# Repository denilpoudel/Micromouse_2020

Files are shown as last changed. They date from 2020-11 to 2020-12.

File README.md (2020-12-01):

# Micromouse 2020

| | Version 1 | Version 2 |
| --- | --- | --- |
| Width | 100mm | ? |
| Height | 80mm | ? |
| MPU | ESP32-WROOM-32U  | ESP32-WROOM-32D |
| IR EMITTER | VSLY5940 | VSLY5940 |
| IR RECIEVER | TSSP58P38 | ? |
| MOTOR | 75:1 Micro Metal Gearbox 6V | 75:1 Micro Metal Gearbox 6V |
| ENCODER | 12 Count Magnetic | 12 Count Magnetic |
| BATTERY |  RDQ 7.6 2s 650mAH LiPo | ? |
| POWER |  TPS63070RNMR @ 7.4V 2A TPS62147RGXR @ 5.0V 2A TPS62147RGXR @ 3.3V 1A | ? |

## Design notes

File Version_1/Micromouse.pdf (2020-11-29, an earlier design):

# Micromouse

Big Rat
November 21, 2020
Denil Poudel
Worth Bistline
Vivian Dinh
Carlos Lazzo
Ken Ny

# Agenda

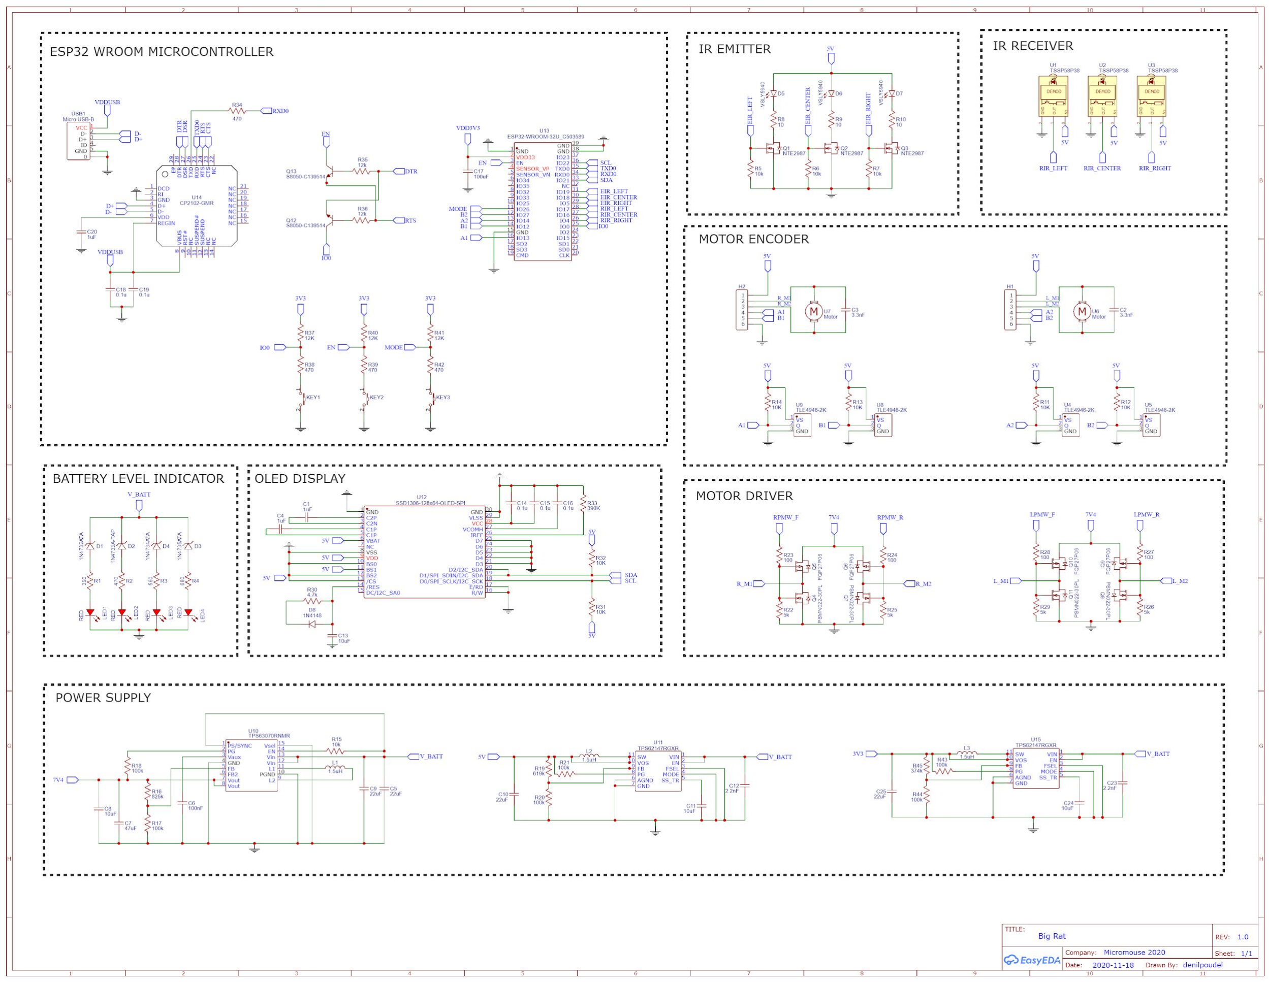
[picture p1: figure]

## - Overview - Design - Microprocessor - Design - Wall Detection - Design - Motor Control - Design - Power - Design - Algorithm - BoM - Schematic

# Big Rat Overview

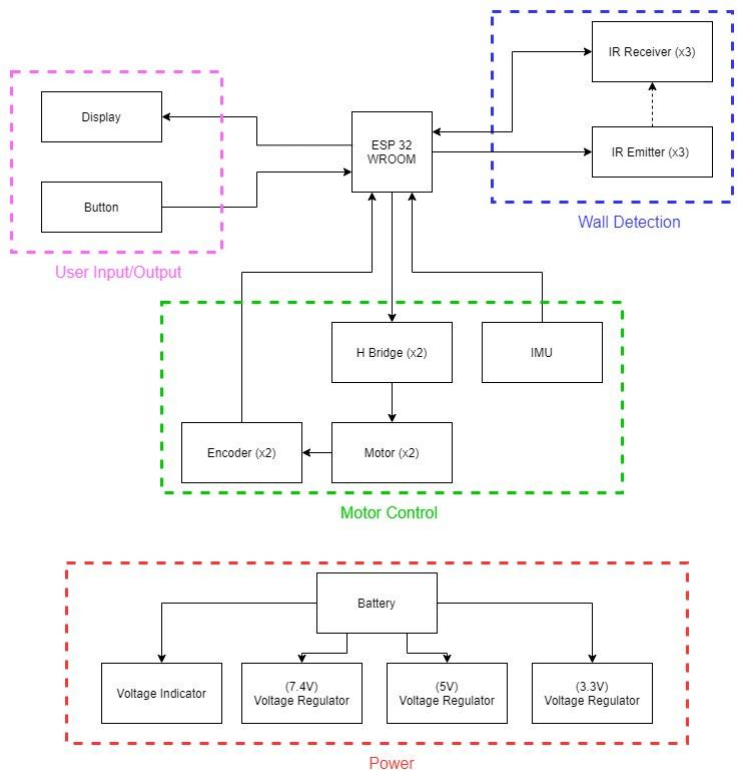
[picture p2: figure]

Dimensions:
Width: | 100mm
Length: | 80mm
| Hardware:
MPU: | ESP32 @240MHz

IR Emitter: VSLY5940 (940nm)
IR Receiver:TSSP58P38 (940nm)
Motor: | 75:1 Micro Metal Gearbox 6V
Encoder: | 12 Count Magnetic
Battery: | RDQ 7.6 2s 650mAH LiPo
Power: | TPS63070RNMR @ 7.4V 2A
| TPS62147RGXR @ 5.0V 2A
| TPS62147RGXR @ 3.3V 1A

# Big Rat Design - Microprocessor

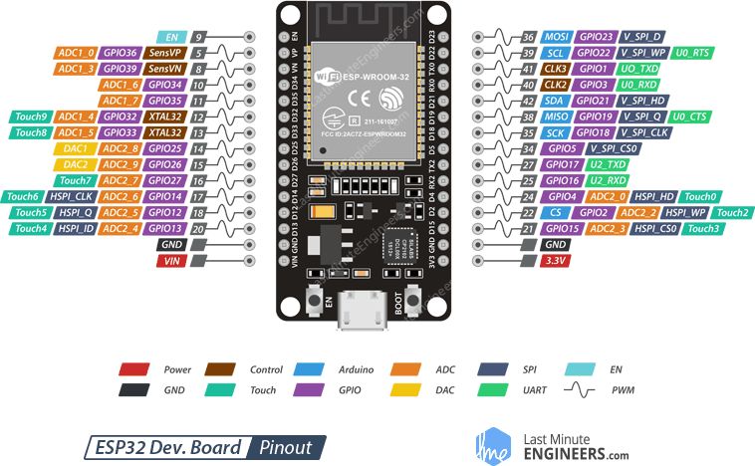
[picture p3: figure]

- ESP32
- Architecture: 32 bit
- Clock: 240MHz
- Core: 2
- PWM: 16 Channels
■ MAX: 40MHz
- Arduino Nano
- Architecture: 16 bit
- Clock: 16MHz
- Core: 1
- PWM: 6 Channels
■ MAX: 490Hz

# Big Rat Design - Wall Detection (IR Emitter)

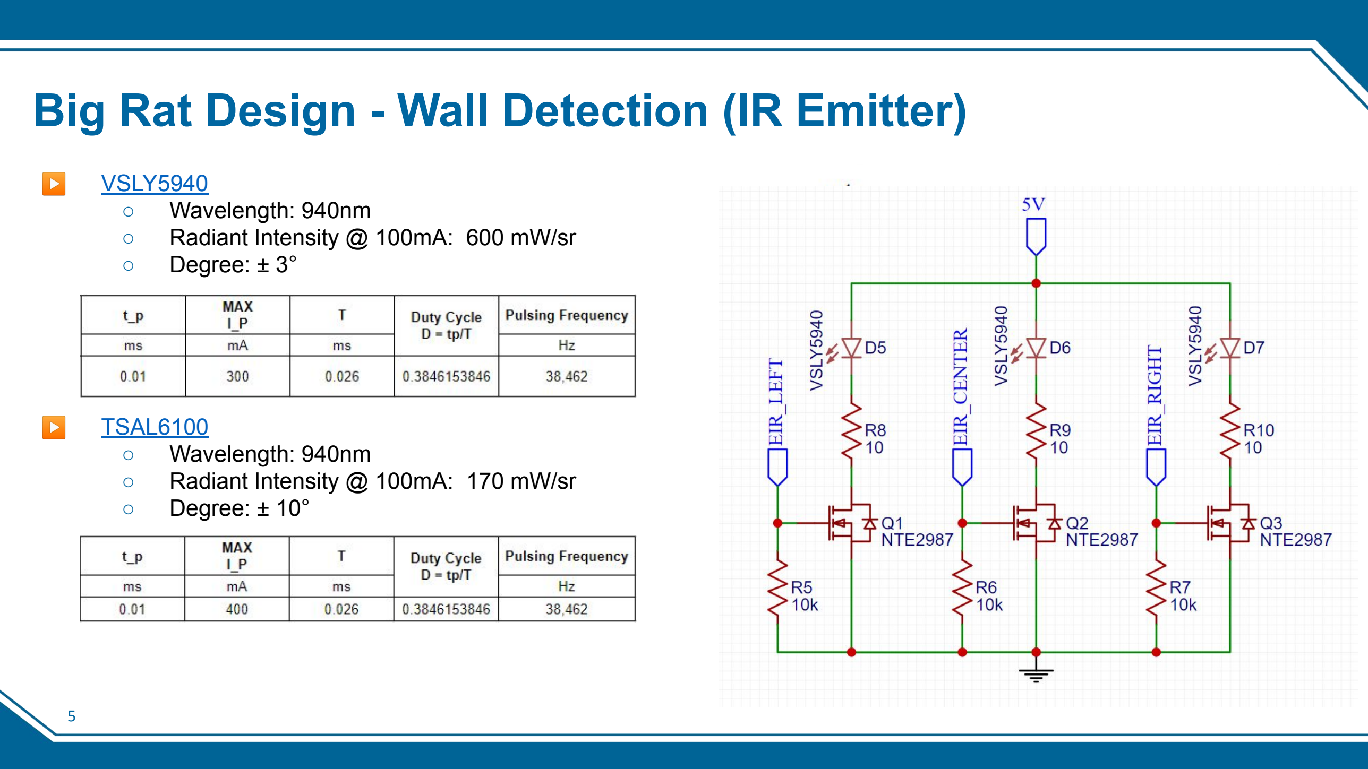
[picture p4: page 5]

- VSLY5940 (https://www.vishay.com/docs/84240/vsly5940.pdf)
- Wavelength: 940nm
- Radiant Intensity @ 100mA: 600 mW/sr
- Degree: ± 3°
- TSAL6100 (https://www.vishay.com/docs/81009/tsal6100.pdf)
- Wavelength: 940nm
- Radiant Intensity @ 100mA: 170 mW/sr
- Degree: ± 10°

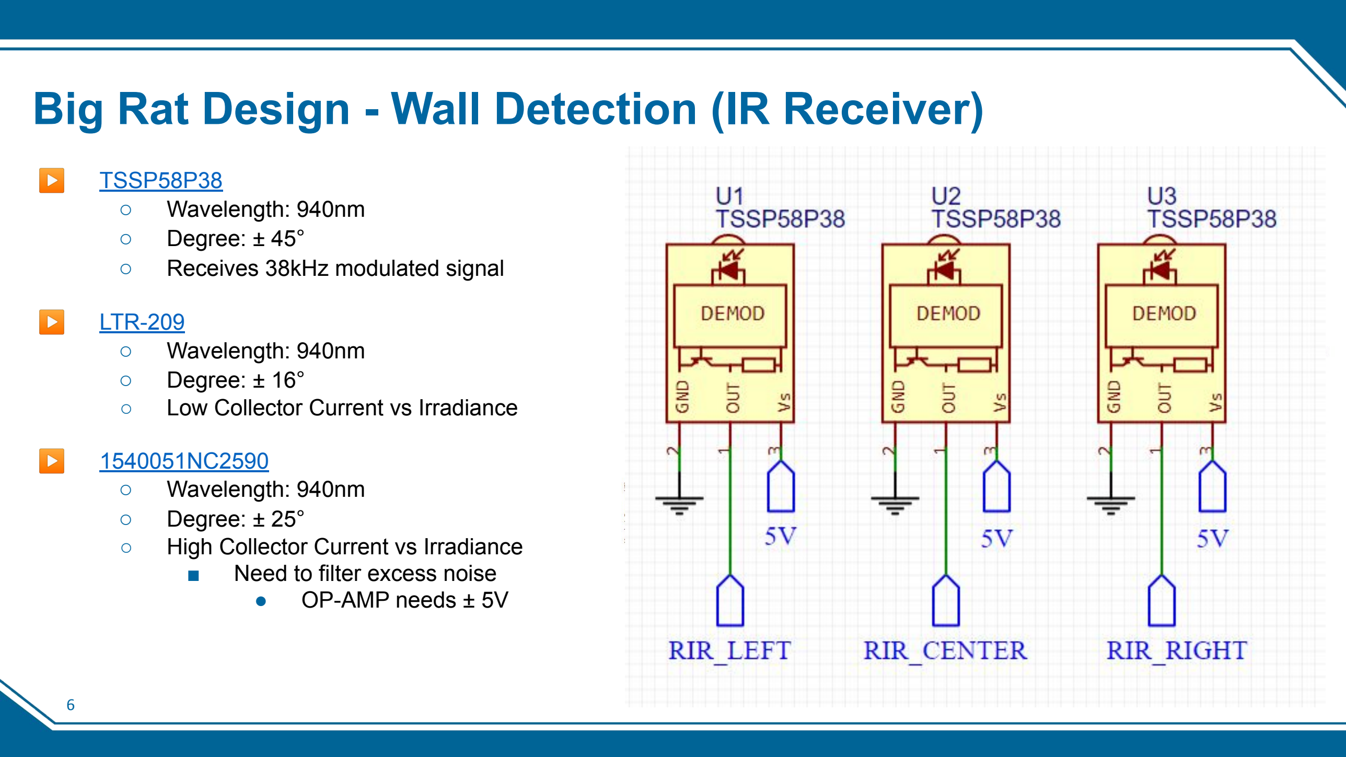
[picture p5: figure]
▶ TSSP58P38; ○ Wavelength: 940nm ○ Degree: ± 45° ○ Receives 38kHz modulated signal; ▶ LTR-209; ○ Wavelength: 940nm ○ Degree: ± 16° ○ Low Collector Current vs Irradiance; ○ Wavelength: 940nm ○ Degree: ± 25° ○ High Collector Current vs Irradiance; Need to filter excess noise; ● OP-AMP needs ± 5V

# Big Rat Design - Wall Detection (IR Receiver)

# Big Rat Design - Motor Control

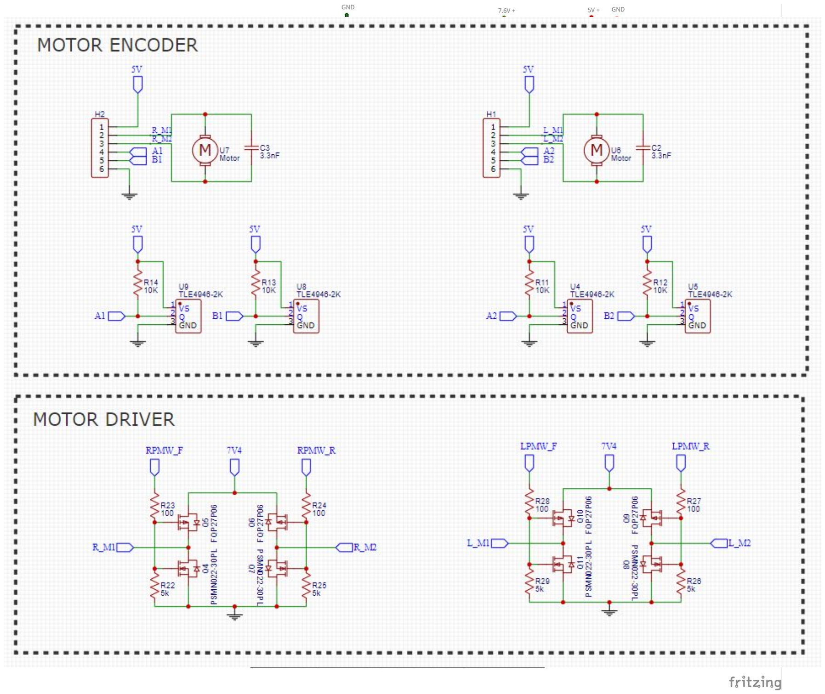
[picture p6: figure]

- H-Bridge
- Discrete H-Bridge
- L298N [Backup]
- Micro Metal Motor
- Brushed DC 6V
- 1:75 Gearbox
- Length: 45 mm
- Magnetic Encoder
- 12 Count [900 Count w/ Gearbox]
- Digital Control System
- Arduino PID Library (https://github.com/owhite/Arduino-PID-control) [ESP32 Compatible]
■ | Store data to EEPROM
■ | Plot data in Python

# Big Rat Design - Power

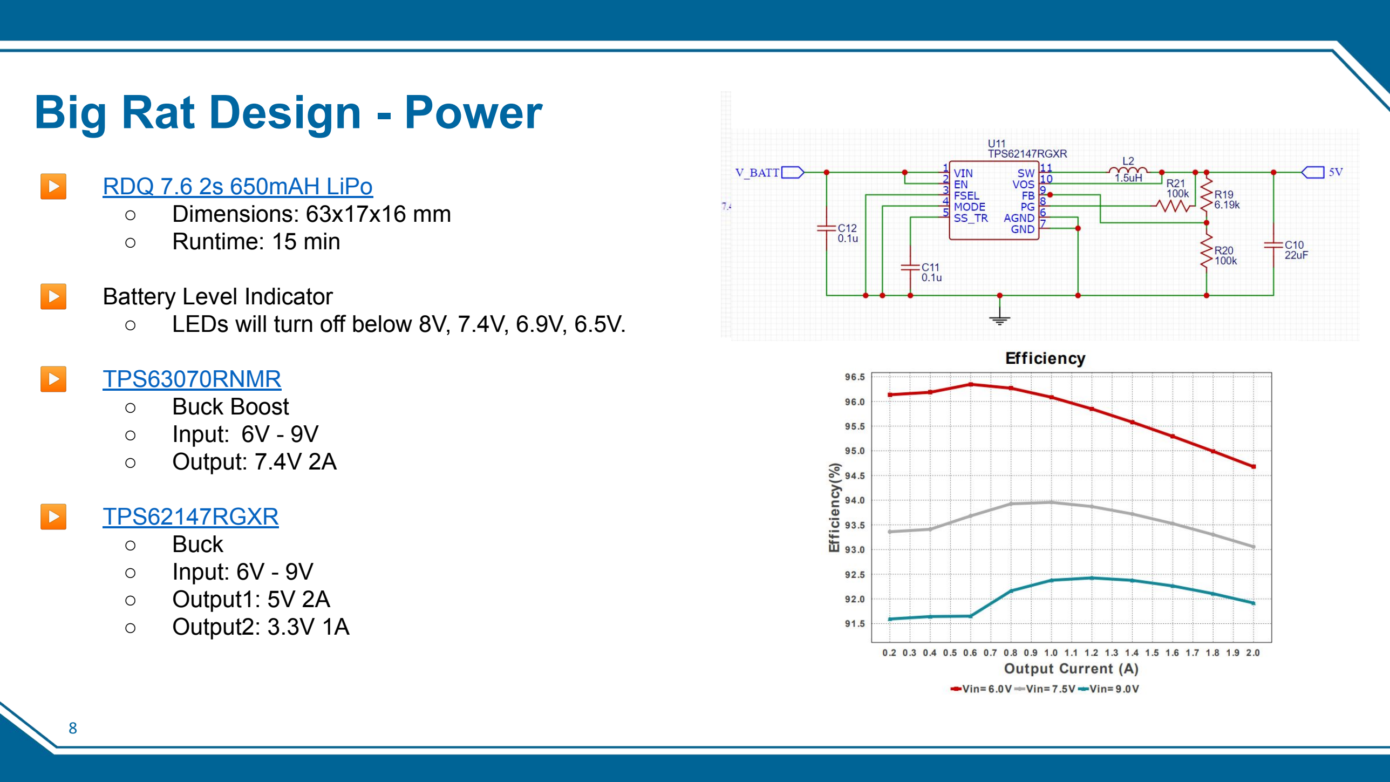
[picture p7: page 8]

Battery Voltage Levels

- RDQ 7.6 2s 650mAH LiPo (https://www.racedayquads.com/collections/mini-batteries/products/rdq-series-7-6v-2s-650mah-60c-lihv-battery-xt30)
- Dimensions: 63x17x16 mm
- Runtime: 15 min
- Battery Level Indicator
- LEDs will turn off below 8V, 7.4V, 6.9V, 6.5V.
- TPS63070RNMR (https://www.ti.com/lit/ds/symlink/tps63070.pdf?ts=1605816152647)
- Buck Boost
- Input: 6V - 9V
- Output: 7.4V 2A
- TPS62147RGXR (https://www.ti.com/lit/ds/symlink/tps62147.pdf?ts=1605822060273)
- Buck
- Input: 6V - 9V
- Output1: 5V 2A
- Output2: 3.3V 1A

Current Draw Calculation

# Big Rat Design - Algorithm

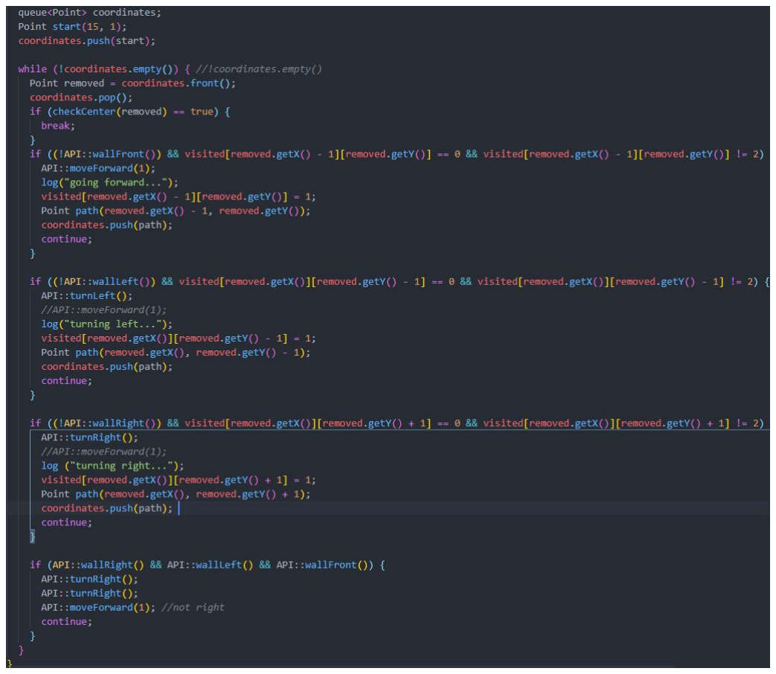
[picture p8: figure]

- MMS Simulator (https://github.com/mackorone/mms)
- Simulation testing C++ Algorithm
- Allows parallel development
- Breadth First Search
- Algorithm:
■ | Selects initial point in graph
■ | Visits all adjacent nodes to the selected
■ | Continues until all nodes in graph is visited
| and marked
- Simplest to implement
■ Does not have the fastest run time
- Will eventually switch algorithms
■ | A*
■ | Flood Fill
■ | Dijkstra’s

# Big Rat - BoM

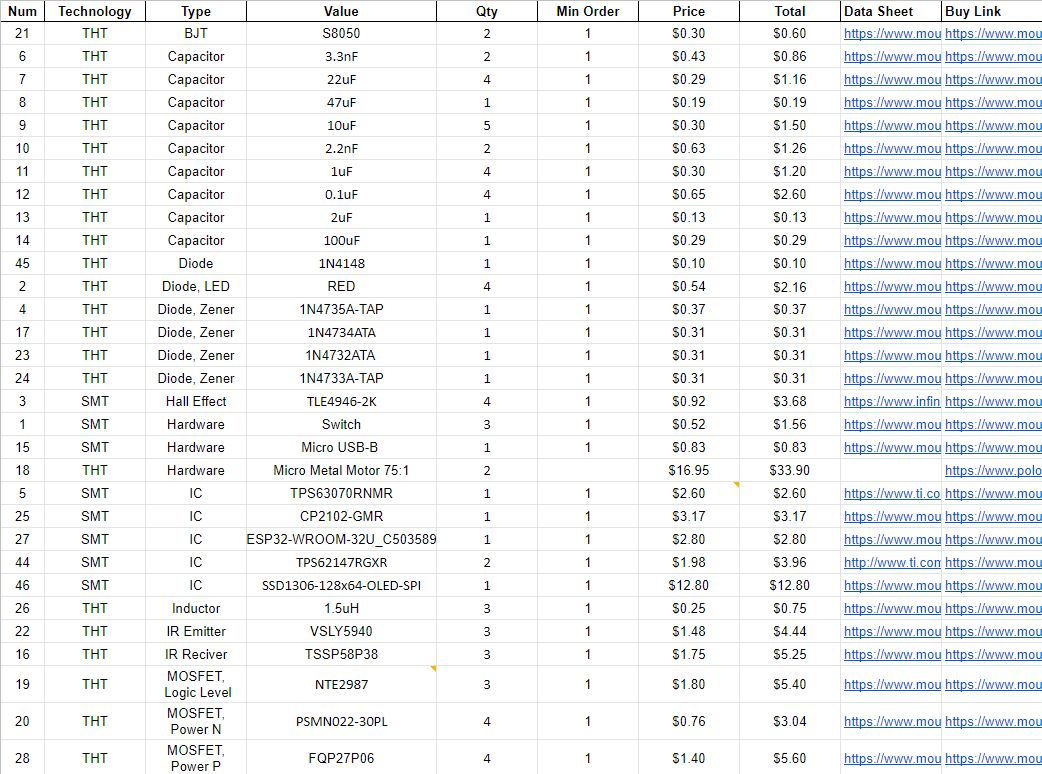
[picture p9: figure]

- Bill Of Material
- All Parts Available from Mouser
- 46 Different Components
■ Mix of THT and SMT ● Eventually all will be SMT
- Total Cost of Components: ~$120.06
- Some components out of stock
■ Working on finding alternatives
- PCB Fabrication
- Custom Home PCB Fabrication by Denil ■ JLCPCB - $10 for 5 Boards ● 3-5 Day Turn Around ● 4 Weeks Shipping

# Questions?

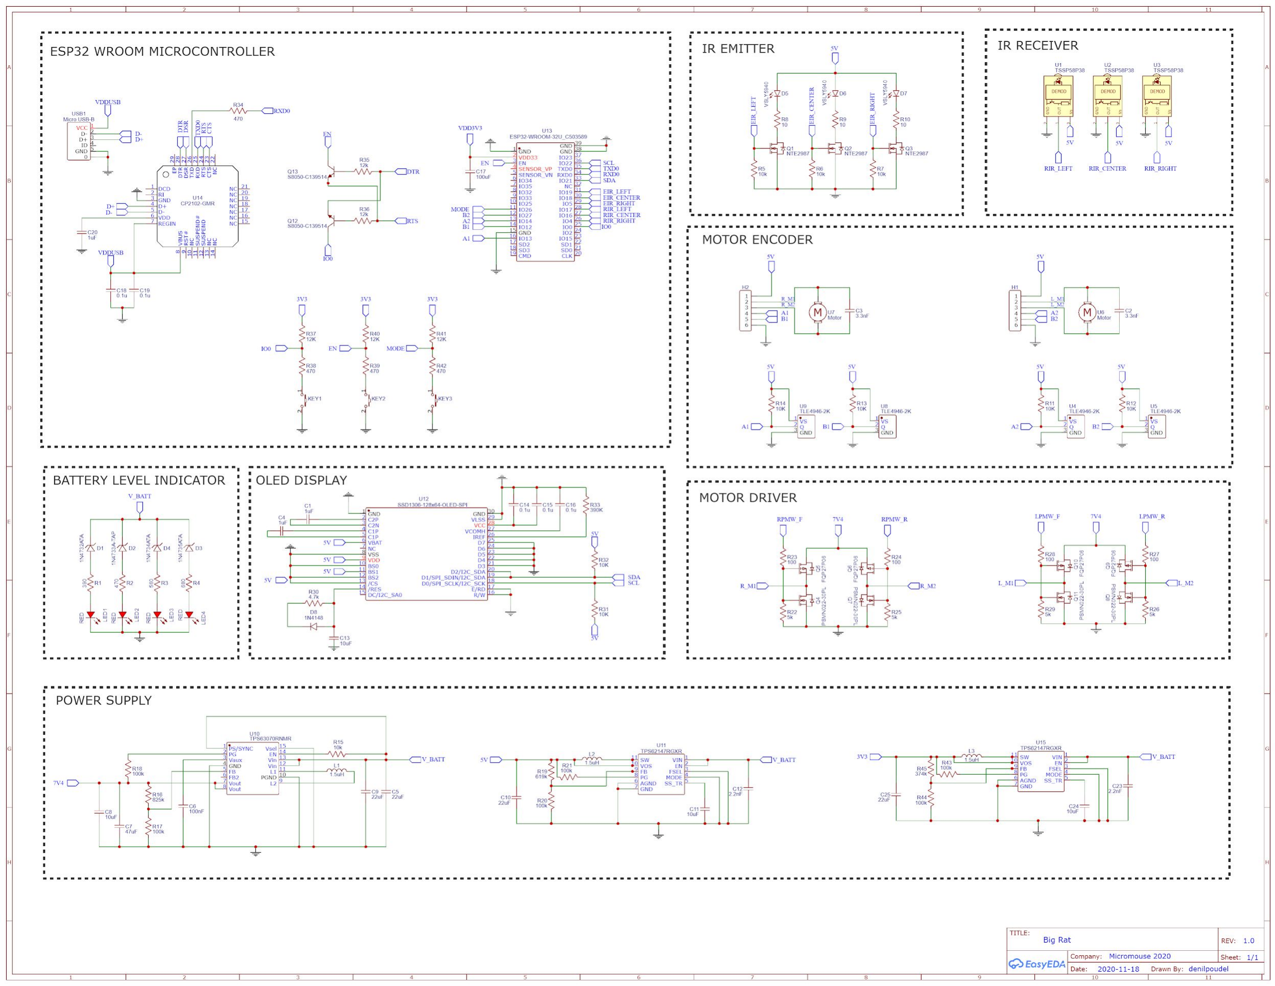
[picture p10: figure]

Schematic (https://drive.google.com/file/d/1DUR6l65qnsQ60jDtrFfjevxRQcCzWgwZ/view?usp=sharing)

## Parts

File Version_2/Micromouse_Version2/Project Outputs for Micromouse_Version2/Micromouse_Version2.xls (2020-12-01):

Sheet: Part List Report
 | Component list |  |  | Bill of Materials for Project [Micromouse_Version2.PrjPcb] (No PCB Document Selected)
 | Source Data From: |  |  | Micromouse_Version2.PrjPcb
 | Project: |  |  | Micromouse_Version2.PrjPcb
 | Variant: |  |  | None
 | Report Date: |  | 11/30/2020 | 15:29
 | Print Date: |  | 2020-11-30 | 15:29:13
# | LibRef | #Column Name Error:' Manufacturer 1 | #Column Name Error:' Manufacturer Part Number 1 | PartType | Description | Footprint | #Column Name Error:' PackageReference | Quantity
1 | CMP-2000-06013-1 |  |  | 10 uF | Chip Capacitor, 10 uF, +/- 10%, 10 V, -55 to 125 degC, 1206 (3216 Metric), RoHS, Tape and Reel | CAPC3216X180X50LL20T25 |  | 4
2 | CMP-2000-06343-1 |  |  | 100 nF | Chip Capacitor, 100 nF, +/- 5%, 25 V, -55 to 125 degC, 1206 (3216 Metric), RoHS, Tape and Reel | CAPC3216X180X55LL20T25 |  | 8
3 | CMP-2000-06441-1 |  |  | 1.5 uH | Low-Profile, High-Current IHLP(R) Inductor, 1.5 uH, +/- 20%, 9 A, -55 to 125 degC, 2-Pin SMD, RoHS, Tape and Reel | VISH-IHLP2525CZER1R5M01_V |  | 2
4 | CMP-2003-04808-1 |  |  | 10K |  | RESC3216X60X45ML10T20 |  | 1
5 | CMP-2003-00010-1 |  |  | 820K |  | RESC3216X70X50LL20T25 |  | 1
6 | CMP-2003-04798-1 |  |  | 100K |  | RESC3216X60X45NL10T20 |  | 2
7 | CMP-2003-04380-1 |  |  | 5K |  | RESC3216X84X51LL20T13 |  | 1
8 | CMP-2003-00847-1 |  |  | 43K |  | RESC3216X70X50NL05T20 |  | 1
9 | CMP-2003-02034-1 |  |  | 2K2 |  | RESC3216X60X45NL10T20 |  | 1
10 | CMP-04918-000001-1 |  |  | TPS63070RNMT | IC REG BCK BST ADJ 2A 15VQFN | FP-RNM0015A-MFG |  | 1
11 | CMP-04918-000108-1 |  |  | TPS563249DDCR | 17-V, 3-A, CONSTANT 1.4-MHZ SYNC | FP-DDC0005A-MFG |  | 1
Approved |  |  |  | Notes |  |  |  | 23

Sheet: Project Information
Project Full Path | C:\Users\Denil\Desktop\Github\Micromouse_2020\Version_2\Micromouse_Version2\Micromouse_Version2.PrjPcb
Project Filename | Micromouse_Version2.PrjPcb
Variant Name | None
Data-Source Filename | Micromouse_Version2.PrjPcb
Data-Source Full Path | C:\Users\Denil\Desktop\Github\Micromouse_2020\Version_2\Micromouse_Version2\Micromouse_Version2.PrjPcb
Title | Bill of Materials for Project [Micromouse_Version2.PrjPcb] (No PCB Document Selected)
Total Quantity | 23
Report Time | 15:29
Report Date | 11/30/2020
Report Date & Tine | 11/30/2020 15:29
Output Name | Bill of Materials
Output Type | BOM_PartType
Output Generator Name | BOM
Output Generator Description | Bill of Materials
Total Actual Price | <Parameter TotalActualPrice not found>
Total Target Price | <Parameter TotalTargetPrice not found>

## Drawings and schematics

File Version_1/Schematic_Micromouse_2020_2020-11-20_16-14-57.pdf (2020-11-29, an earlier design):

# ESP32 WROOM MICROCONTROLLER

IR EMITTER | IR RECEIVER

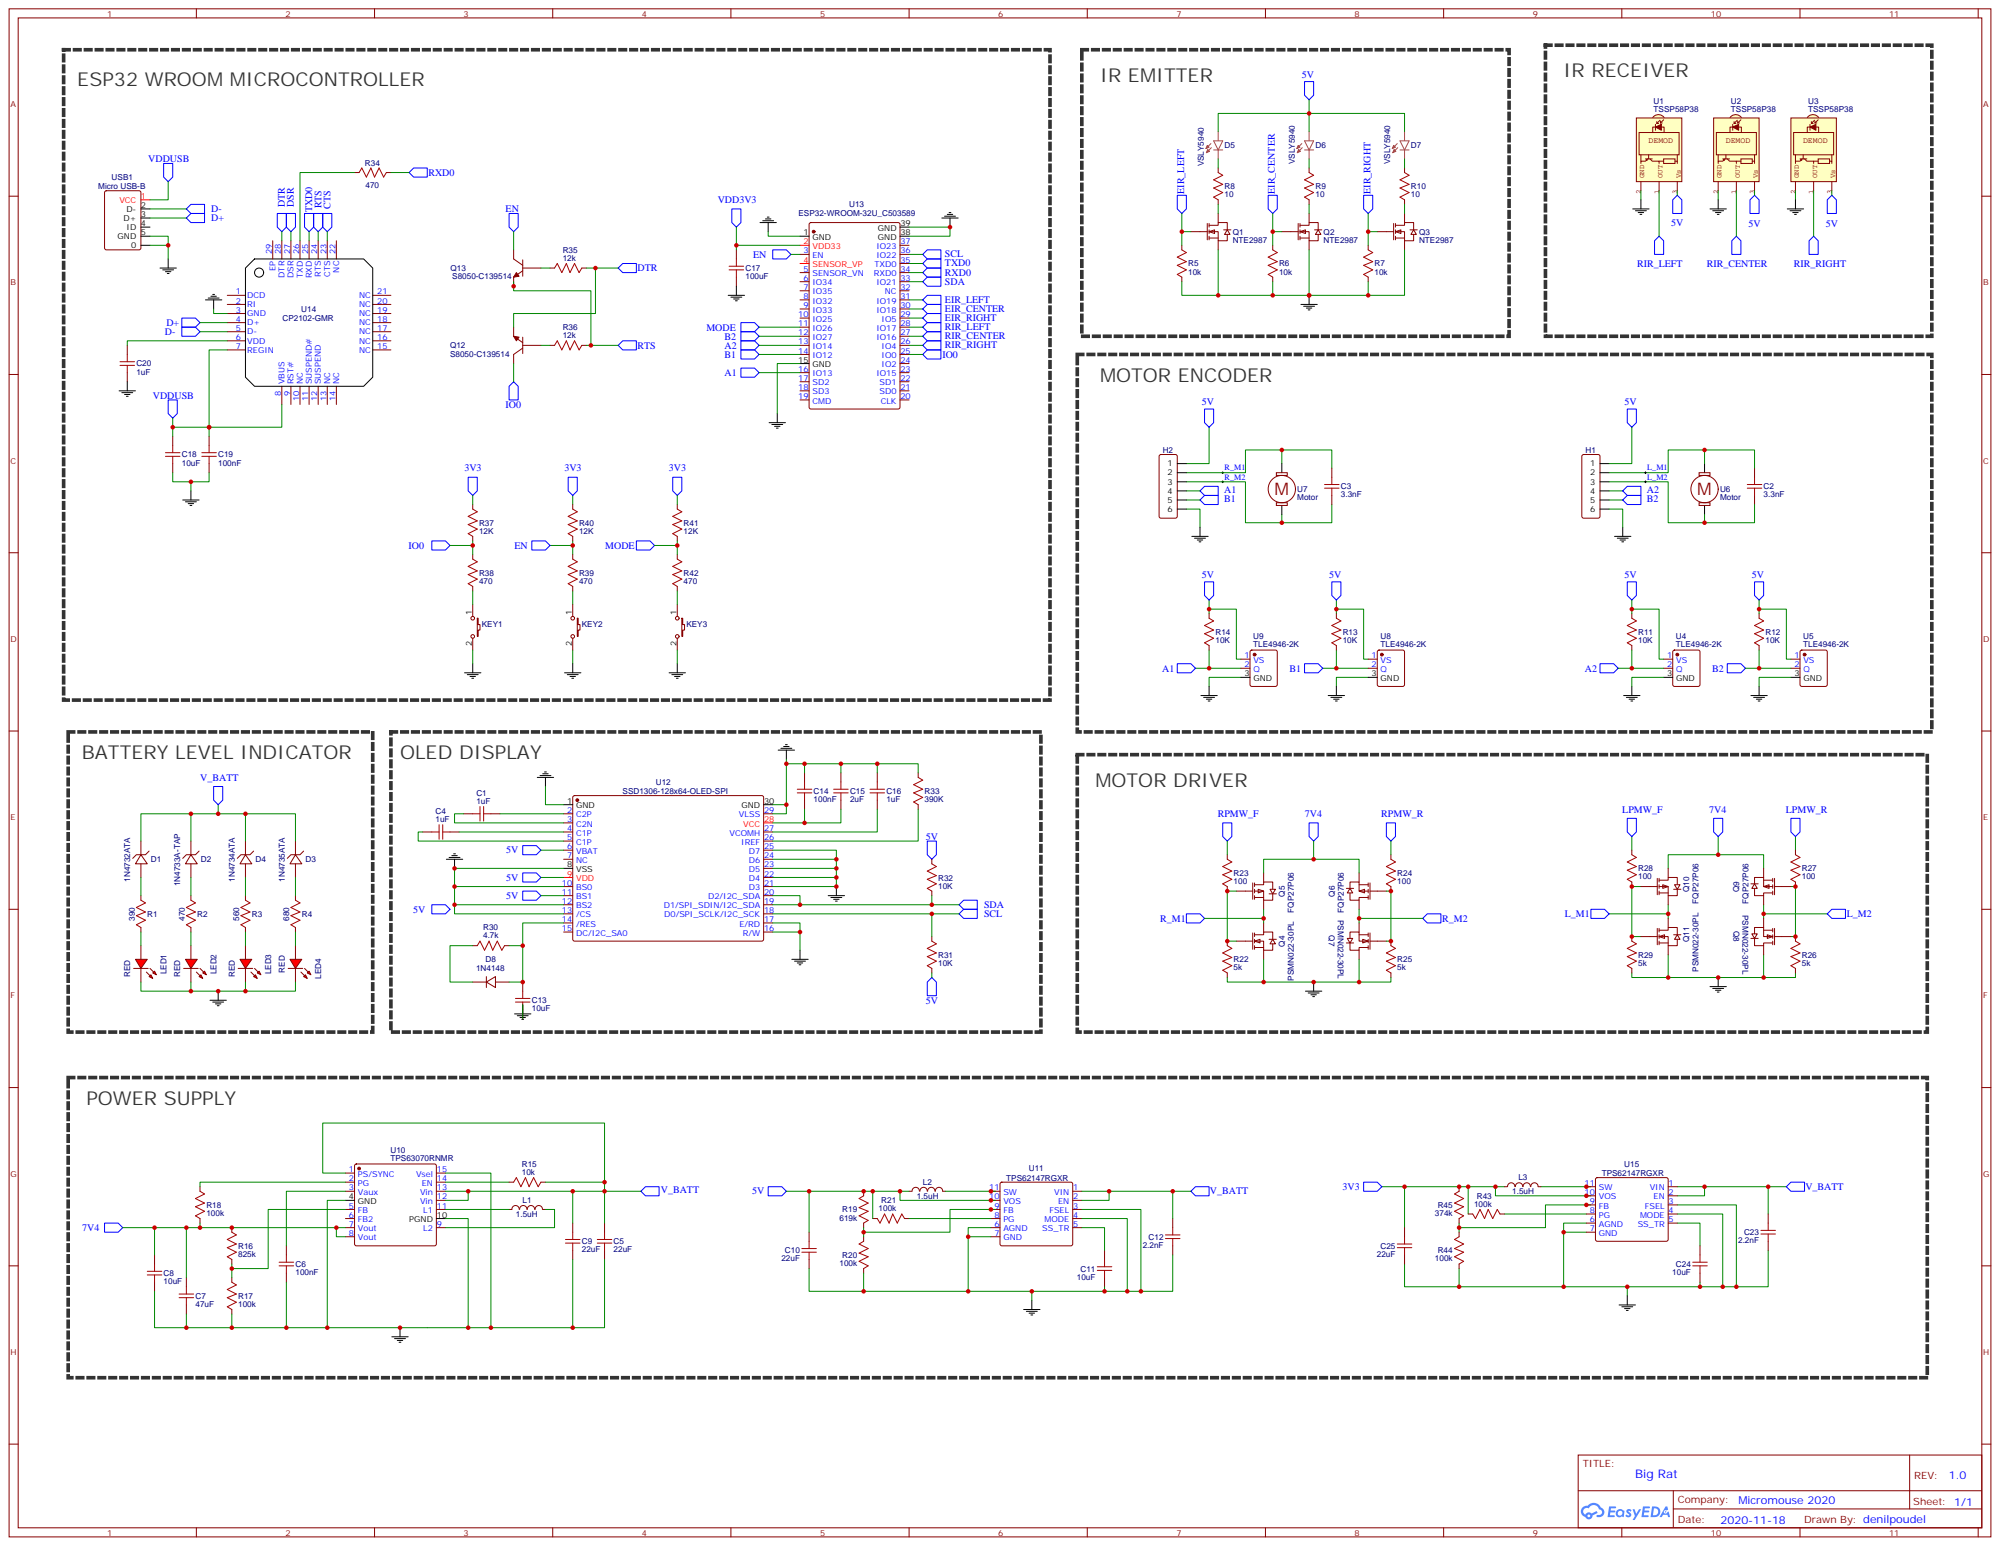
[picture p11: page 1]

NC 22 CTS 23 RTS 24 RXD 25 TXD 26 DSR 27 DTR 28 EP 29

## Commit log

2020-11-29 Version 1 Initial Commit
    Added files from version 1
    [h_bridge.fzz, micromouse.fzz]
2020-12-01 SMPS 7V4 and SMPS 3V3 Done
    SMPS 7V4 and SMPS 3V3 Done
    Started on ESP32 WROOM 32D
    [Micromouse_Version2.PcbDoc, Micromouse_Version2.PcbLib, Micromouse_Version2.PrjPcb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]
2020-12-02 USB Micro + USB to UART driver
    [Components - 02.12.20 - 13.48.PcbLib, Components - 02.12.20 - 13.48.SchLib, Micromouse_Version2.PcbLib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]
